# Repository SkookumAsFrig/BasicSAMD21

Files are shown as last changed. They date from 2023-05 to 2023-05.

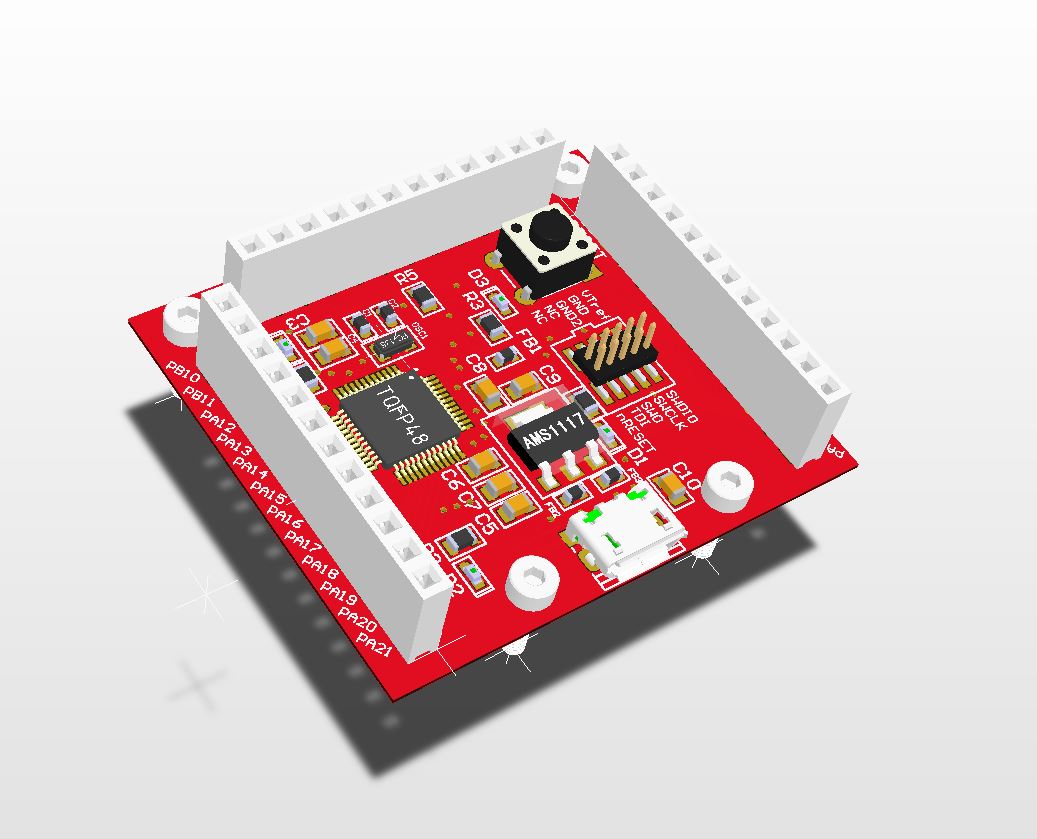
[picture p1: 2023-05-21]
Project Outputs for BasicSAMD21/3D.JPG

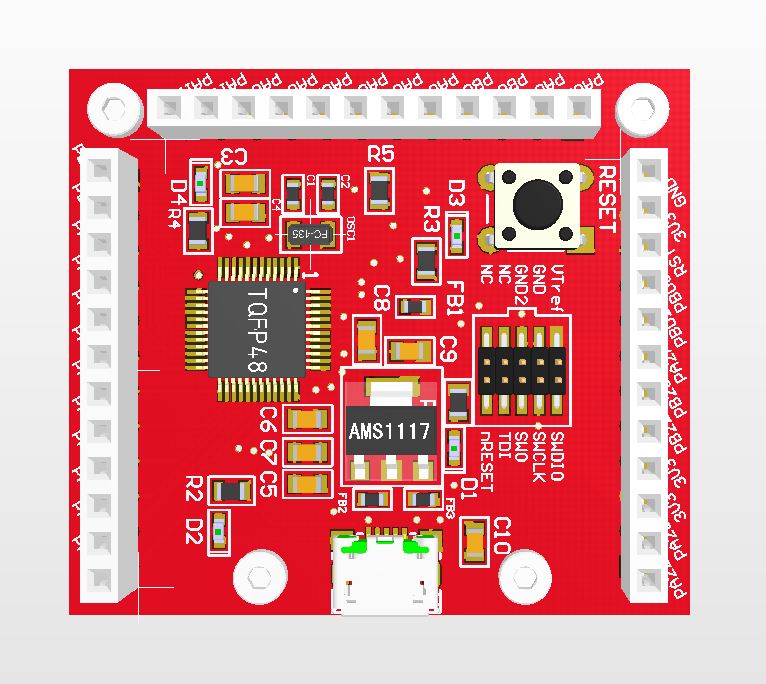
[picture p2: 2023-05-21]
Project Outputs for BasicSAMD21/Top.JPG

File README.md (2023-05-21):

# BasicSAMD21
Basic SAMD21 ARM Cortex M0 development board Altium porject






PROJECT DESCRIPTION

Small footprint SAMD21G18A MCU development board, measuring only 45x40mm. Based on Cortex M0, it is Arduino compatible with JTag ISP functionality. Completed in 24 hours, from start of schematics library to submission to manufacturer. Fabricated in 4 days with professional surface mount assembly.

CHALLENGES AND ACCOMPLISHMENTS

This project was done during a holiday trip in China, as a feeler for the PCBA manufacturing pipeline there. As the results show, it was extremely efficient, as I got the boards assembled and delivered within a week of beginning the design. This gave me invaluable experience with the end-to-end process of making PCBAs, especially with tight time constraints. I am now familiar with how long each process takes, and why.

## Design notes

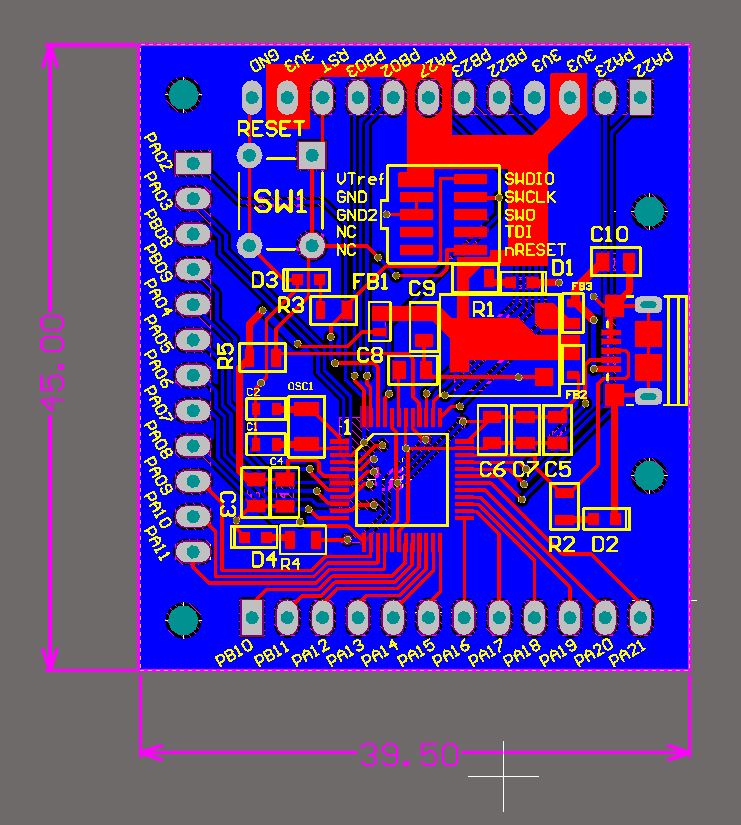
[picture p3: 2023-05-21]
Project Outputs for BasicSAMD21/Layout.JPG

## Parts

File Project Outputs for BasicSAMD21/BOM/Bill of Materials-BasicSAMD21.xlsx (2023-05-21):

Comment | Description | Designator | Footprint | LibRef | Quantity
15pF_0603 | 15pF_0603 | C1, C2 | C0603 | 15pF_0603 | 2
10uF/16V | CAP CER 10UF 16V X5R 0805 | C3, C6, C9, C10 | C0805 | C2012X5R1C106M125AC | 4
100nF | CAP CER 0.1UF 50V X7R 0805 | C4, C5, C7 | C0805 | C2012X7R1H104K085AA | 3
1uF/25V | CAP CER 1UF 25V X5R 0805 | C8 | C0805 | C2012X5R1E105K125AA | 1
Orange | LED ORANGE DIFFUSED 0603 SMD | D1, D2, D3, D4 | LED_0603 | LO L29K-H2K1-24-Z | 4
FerriteBead0R800mA_0603 | FerriteBead0R800mA_0603 | FB1, FB2, FB3 | C0603 | FerriteBead0R800mA_0603 | 3
M2Hole | M2Hole | H1, H2, H3, H4 | M2Hole | M2Hole | 4 | 非贴片、不需要assembly
2.54HDR_12POS | 2.54HDR_12POS | HDR1, HDR3, HDR4 | DIP12 | 2.54HDR_12POS | 3
JTAG10Pin | JTAG10Pin | HDR2 | JTAG10 | JTAG_10Pin | 1
10118193-0001LF | CONN USB MICRO B RECPT SMT R/A | J1 | 10118193 | 10118193-0001LF | 1
LDO_AMS11173.3_SOT-223 | LDO_AMS11173.3_SOT-223 | LDO1 | SOT223 | LDO_AMS11173.3_SOT-223 | 1
FC-135_32KHZ | 32.768kHz ±20ppm Crystal 12.5pF 50 kOhm -40°C ~ 85°C Surface Mount 2-SMD, No Lead (DFN, LCC) | OSC1 | FC-135 | FC-135R32.7680KA-A3 | 1
1k R | RES SMD 1K OHM 1% 1/8W 0805 | R1, R2, R3, R4, R5 | R0805 | RC0805FR-071KL | 5
1825910-6 | SWITCH TACTILE SPST-NO 0.05A 24V | SW1 | 1825910-6 | 1825910-6 | 1
ATSAMD21G18 | IC MCU 32BIT 256KB FLASH 48TQFP | U1 | TQFP48 | ATSAMD21G18A-AUT | 1

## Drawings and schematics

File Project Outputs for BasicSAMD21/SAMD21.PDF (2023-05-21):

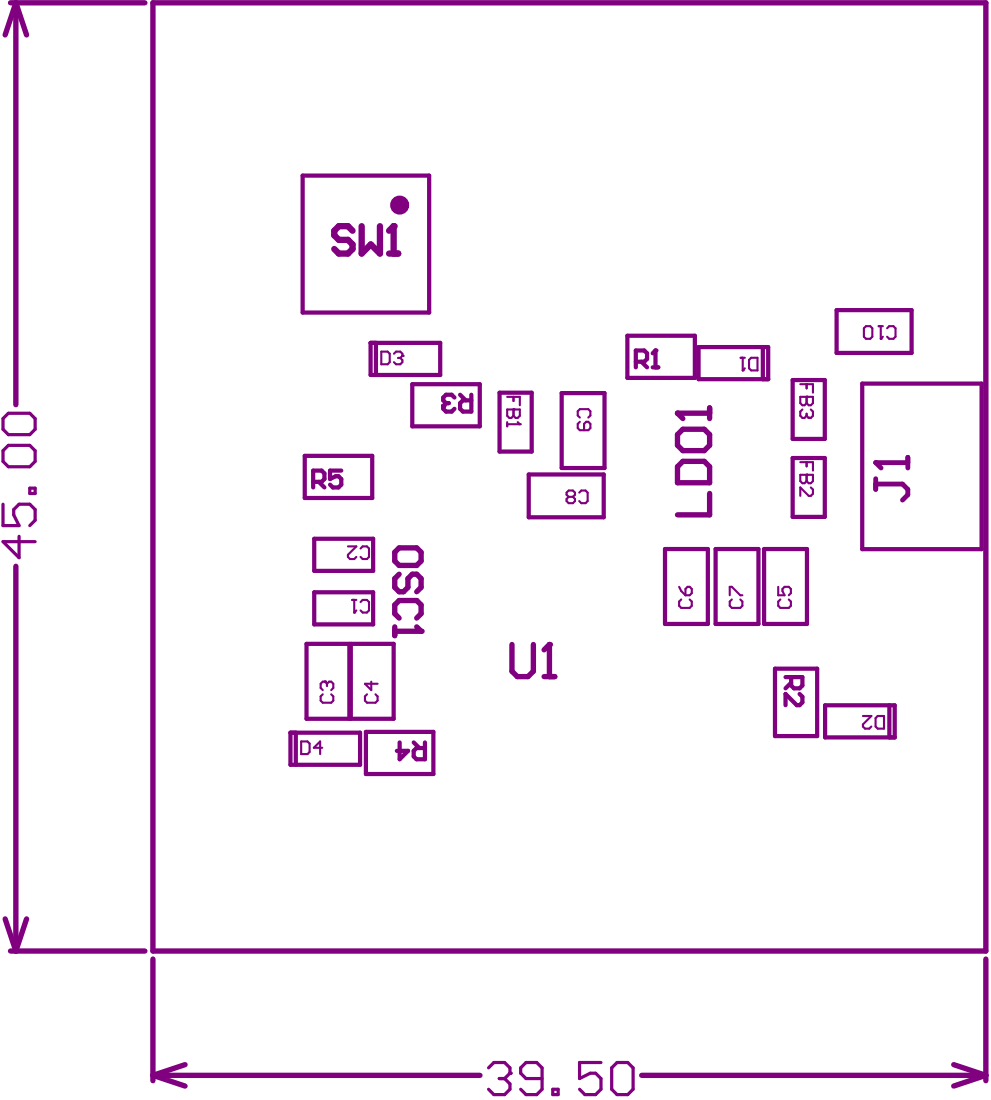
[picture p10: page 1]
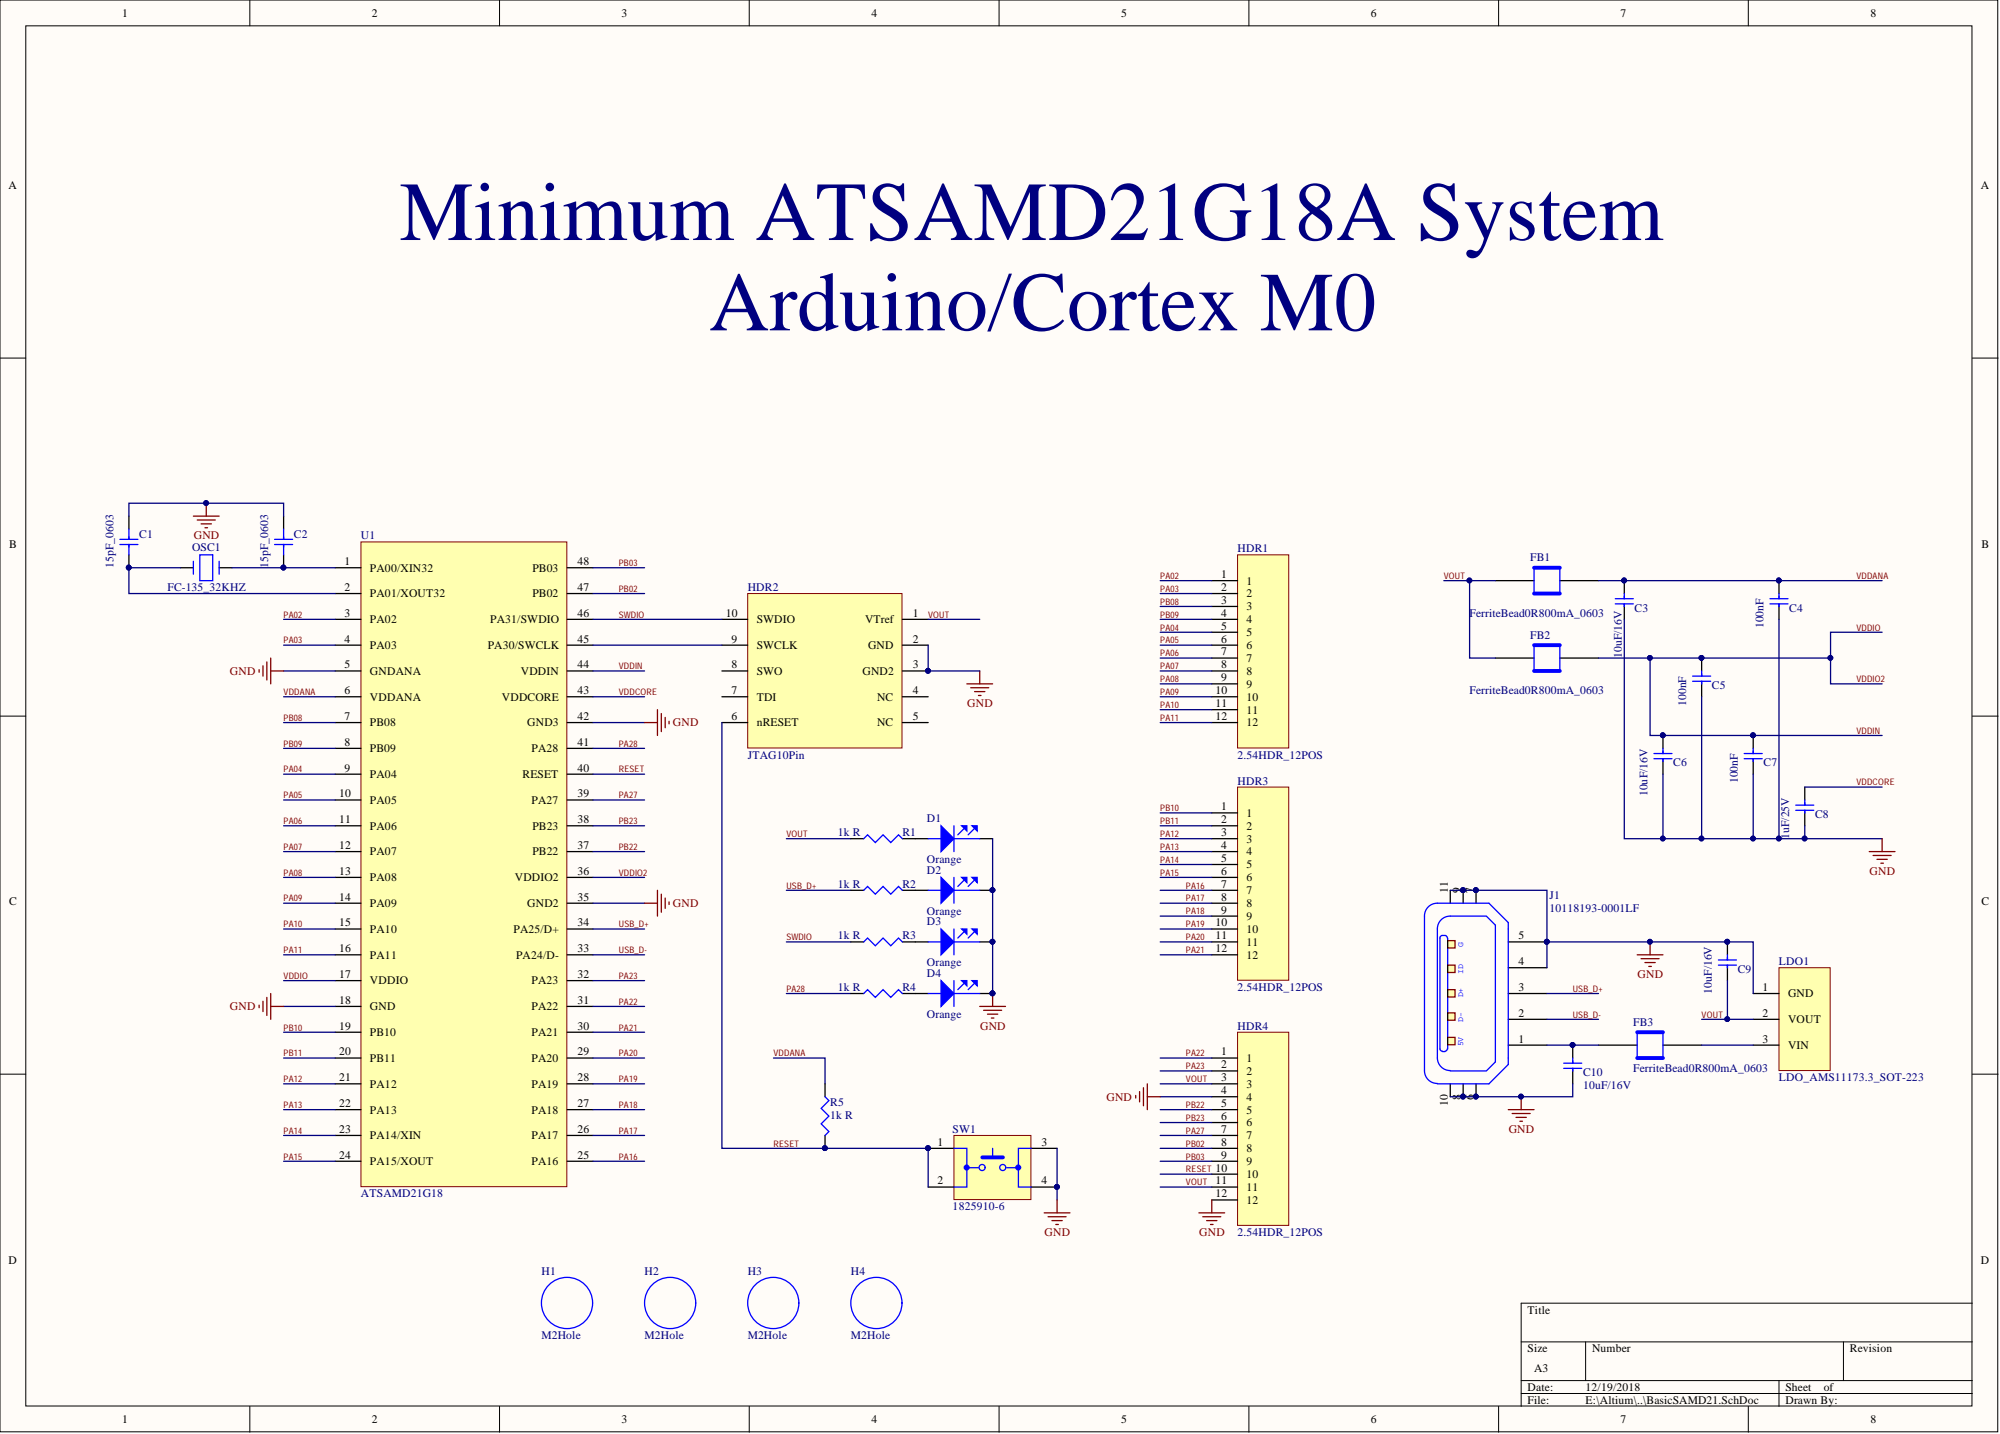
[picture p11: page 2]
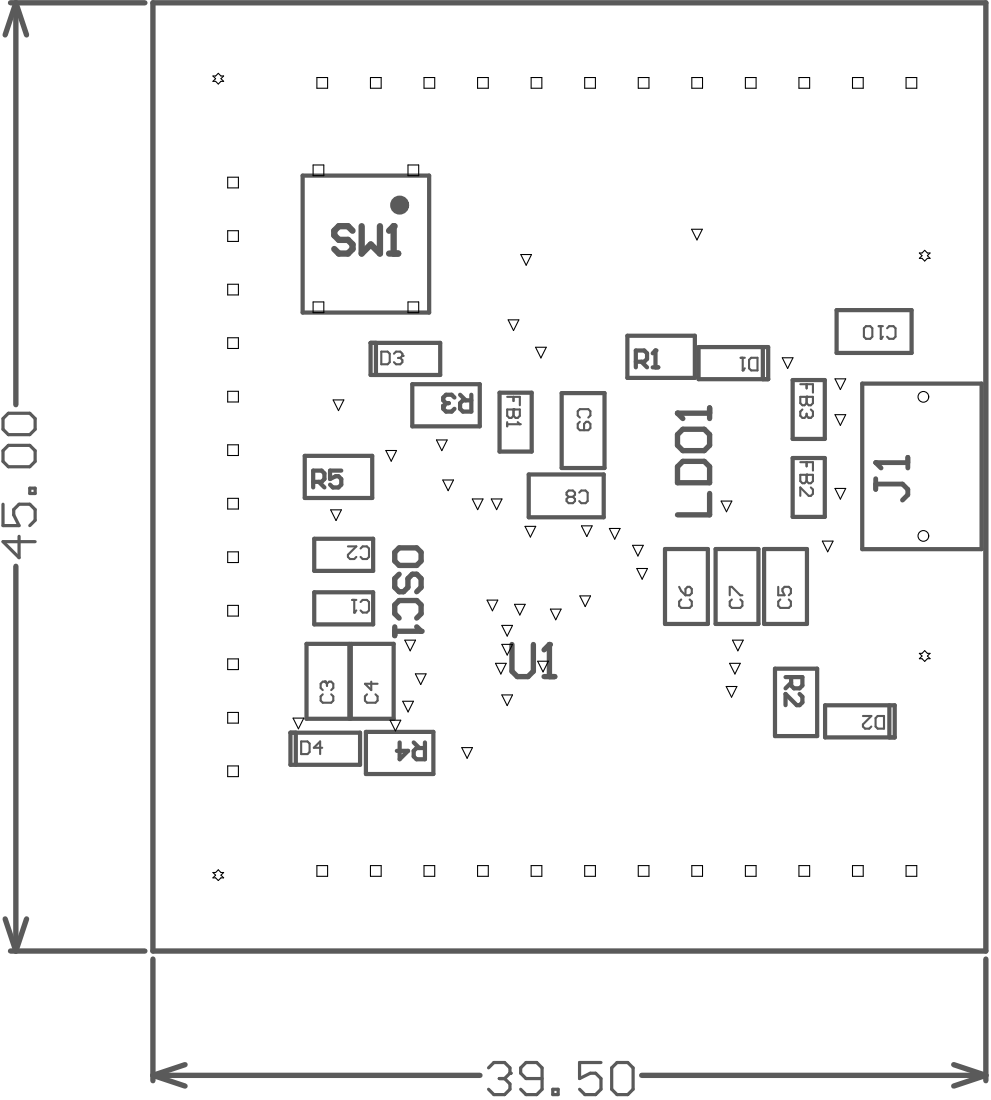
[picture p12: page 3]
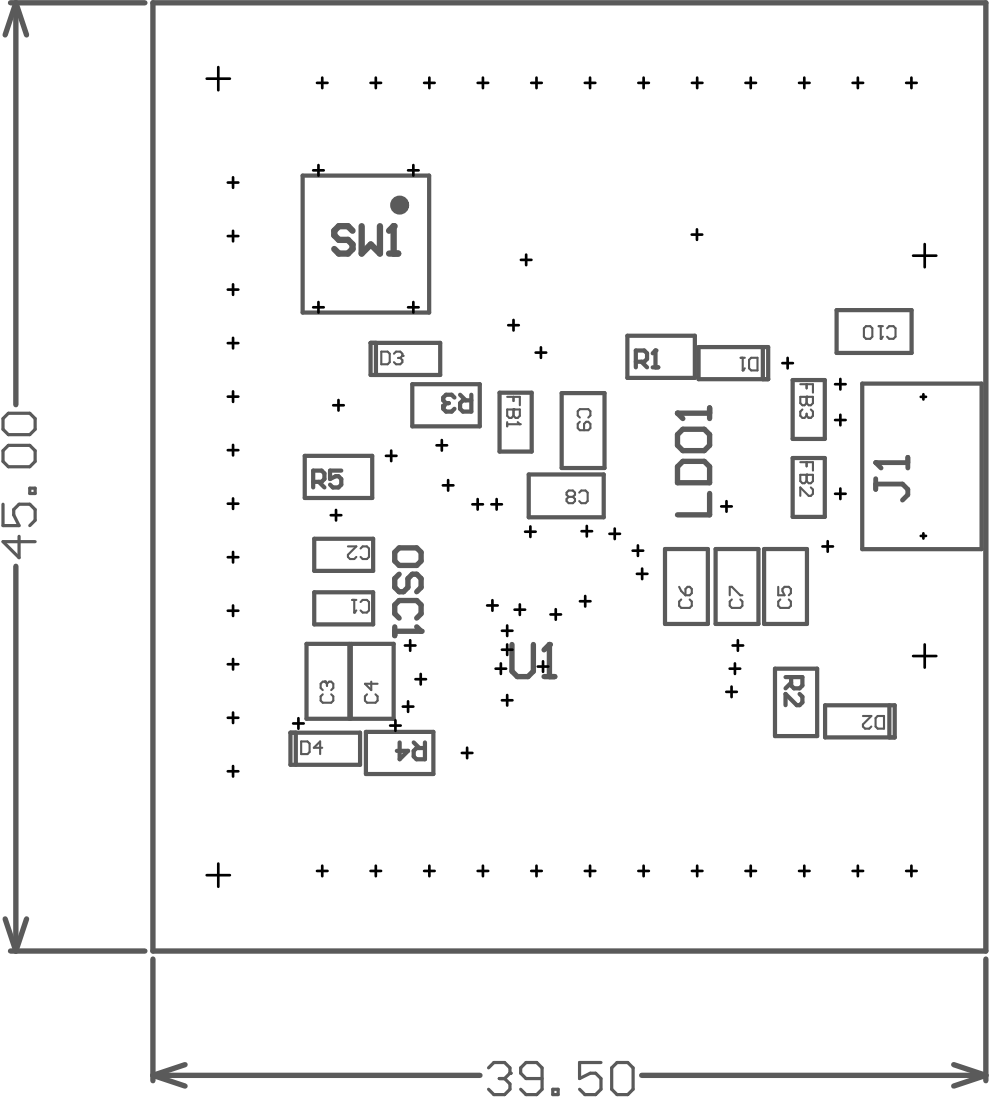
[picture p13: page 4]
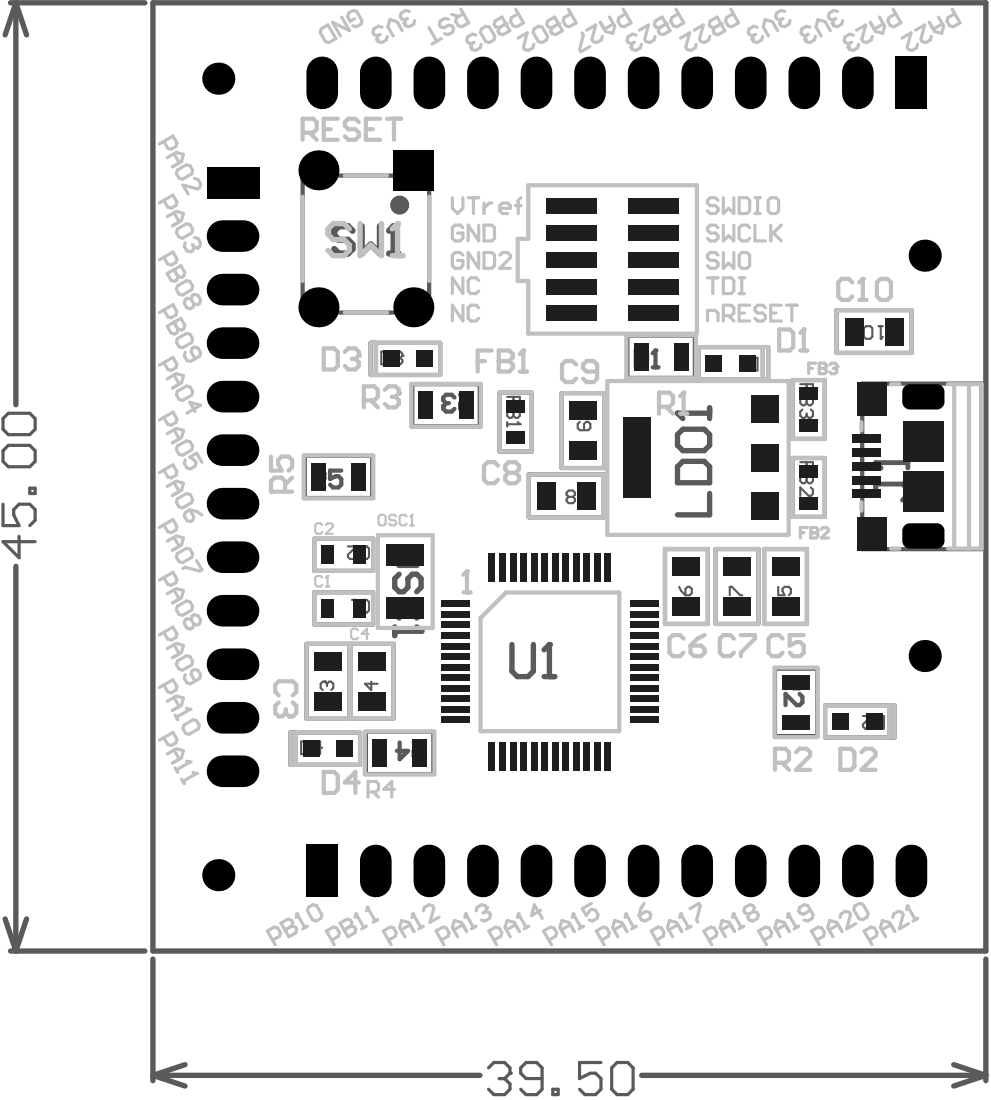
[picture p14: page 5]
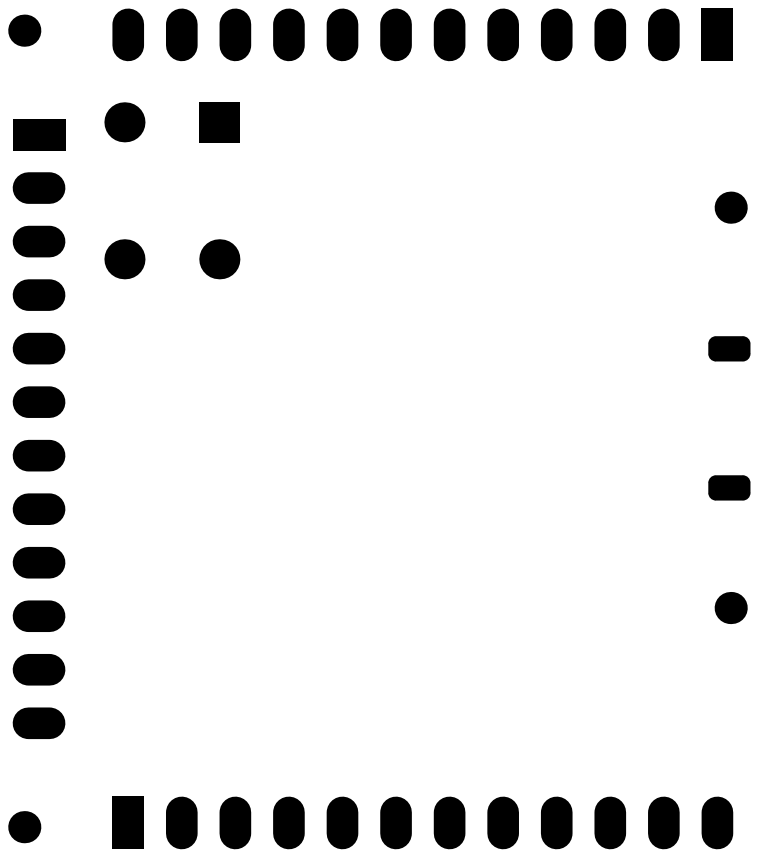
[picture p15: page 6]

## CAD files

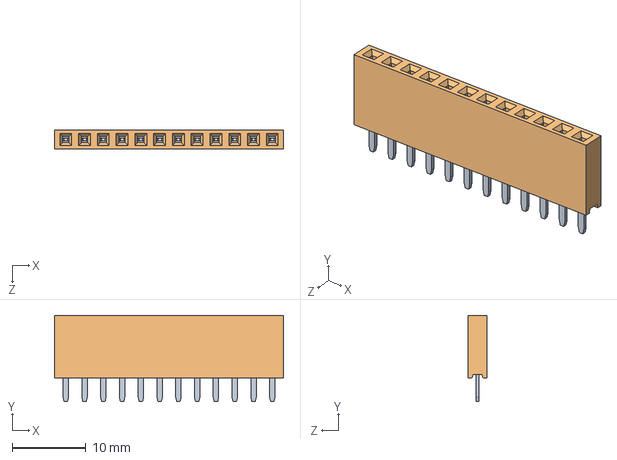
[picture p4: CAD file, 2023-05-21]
CAD/_ _ _C121LFBN-RC/_ _ _C121LFBN-RC.STEP
31.0 x 11.7 x 2.54 mm

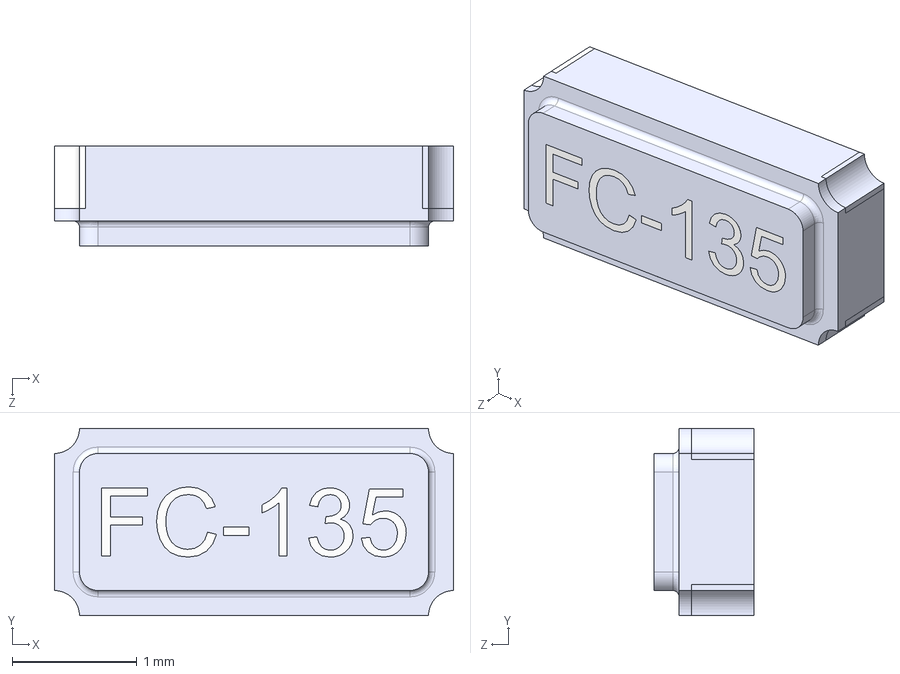
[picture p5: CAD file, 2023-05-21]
CAD/User Library-Crystal FC-135/User Library-Crystal FC-135.STEP
3.20 x 1.50 x 0.8 mm
User Library-Crystal FC-135_Body
User Library-Crystal FC-135_Pin 2
User Library-Crystal FC-135_Pin 1
User Library-Crystal FC-135_Tekst Inlay

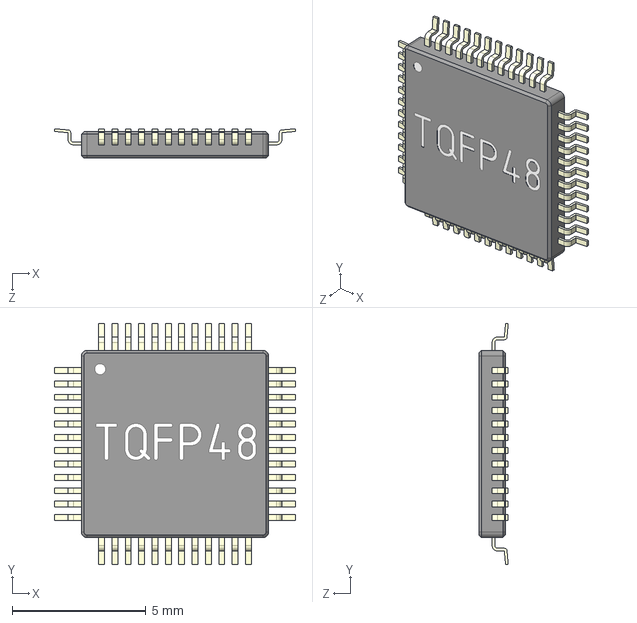
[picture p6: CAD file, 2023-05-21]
CAD/User Library-TQFP48.step
9.02 x 9.02 x 1.10 mm

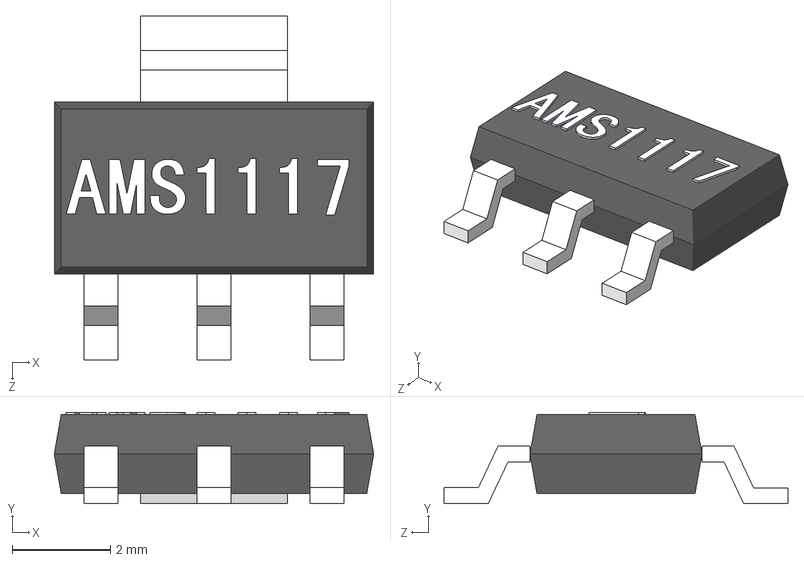
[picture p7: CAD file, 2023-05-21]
CAD/User Library-AMS1117.step
6.50 x 1.86 x 7.00 mm

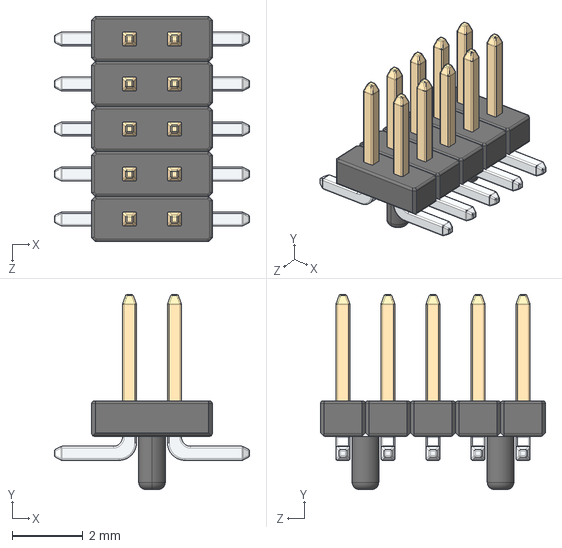
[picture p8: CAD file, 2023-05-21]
CAD/M50-3610542.STEP
5.50 x 5.50 x 6.35 mm
M50-360-Pin x 5
Alignment-Pin x 2

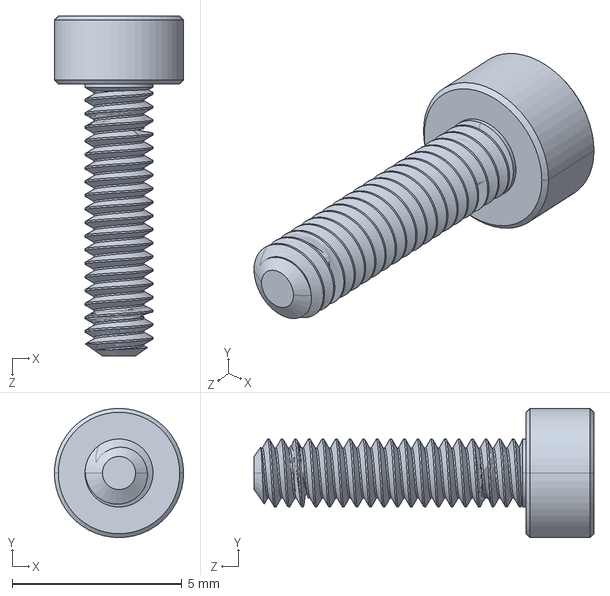
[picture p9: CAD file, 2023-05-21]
CAD/91290A015_BLACK-OXIDE CLASS 12.9 SOCKET HEAD CAP SCREW.STEP
3.80 x 3.80 x 10.0 mm
